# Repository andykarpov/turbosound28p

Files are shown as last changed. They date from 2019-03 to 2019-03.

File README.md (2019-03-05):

# Turbosound AVR AY Emul v1.0

TurboSound Emulator on 2x Atmega8A chips based on http://www.avray.ru project.

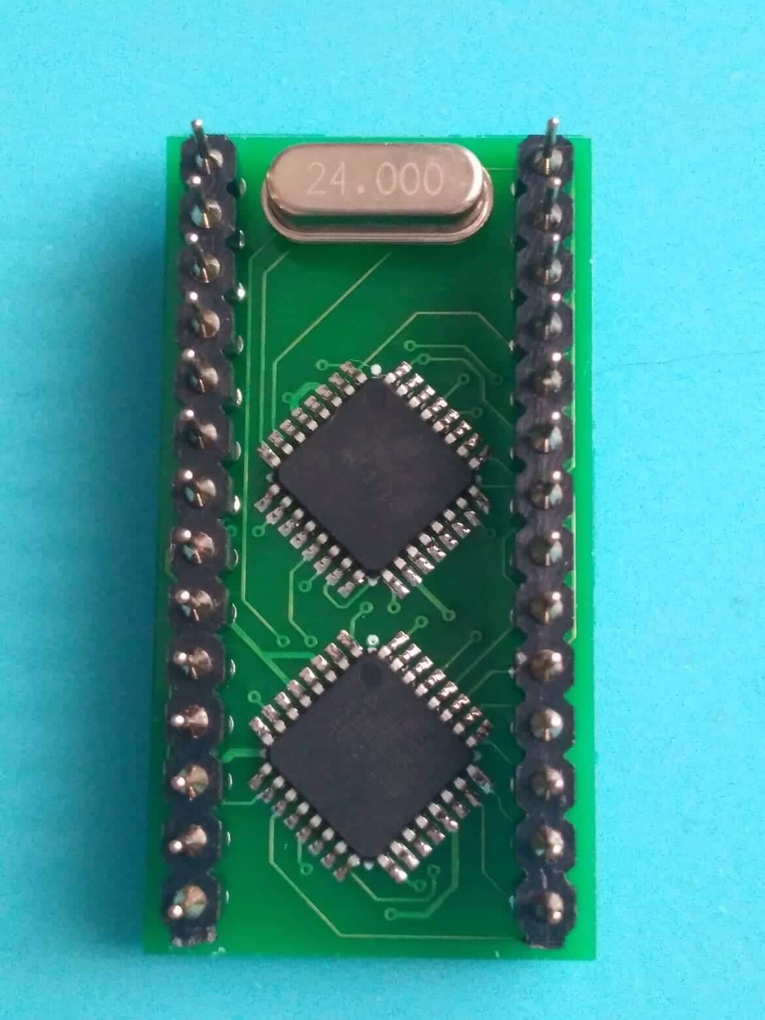
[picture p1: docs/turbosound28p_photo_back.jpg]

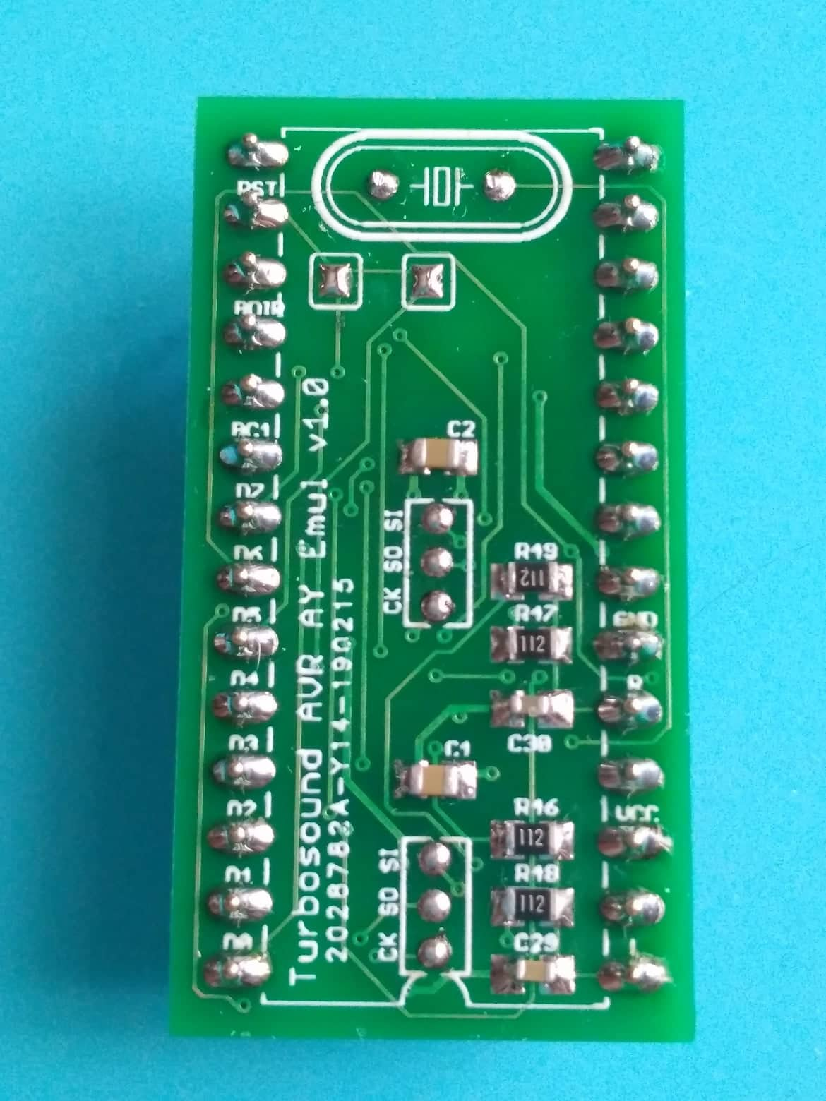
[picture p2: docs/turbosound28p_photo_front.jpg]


## How to upload the firmware
Due to there is no room for ISP connectors on the board, you need to solder a few wires directly on the board and connect them with your programmer:
- GND, VCC and RESET signals 
- CK, SO, SI as SCLK, MISO and MOSI signals 
- Do not forget to bridge solder jumpers

### Uploading:

Use avrdude and USBAsp programmer to upload firmware for each chip:

avrdude -p atmega8 -c USBasp -U flash:w:emul_230_turbosound_chip0.hex -U eeprom:w:Conf_parallel_24MHz_1_75Mhz.hex -U lfuse:w:0xCE:m -U hfuse:w:0xCF:m

avrdude -p atmega8 -c USBasp -U flash:w:emul_230_turbosound_chip1.hex -U eeprom:w:Conf_parallel_24MHz_1_75Mhz.hex -U lfuse:w:0xCE:m -U hfuse:w:0xCF:m

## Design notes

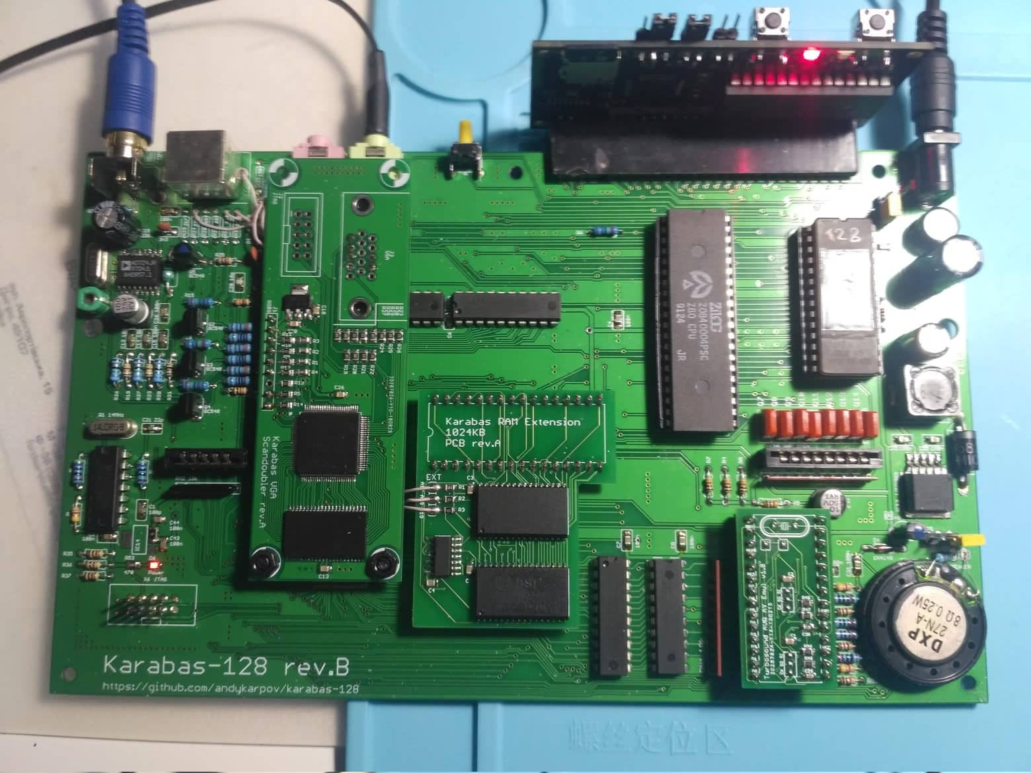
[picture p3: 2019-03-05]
docs/turbosound28p_photo_karabas.jpg

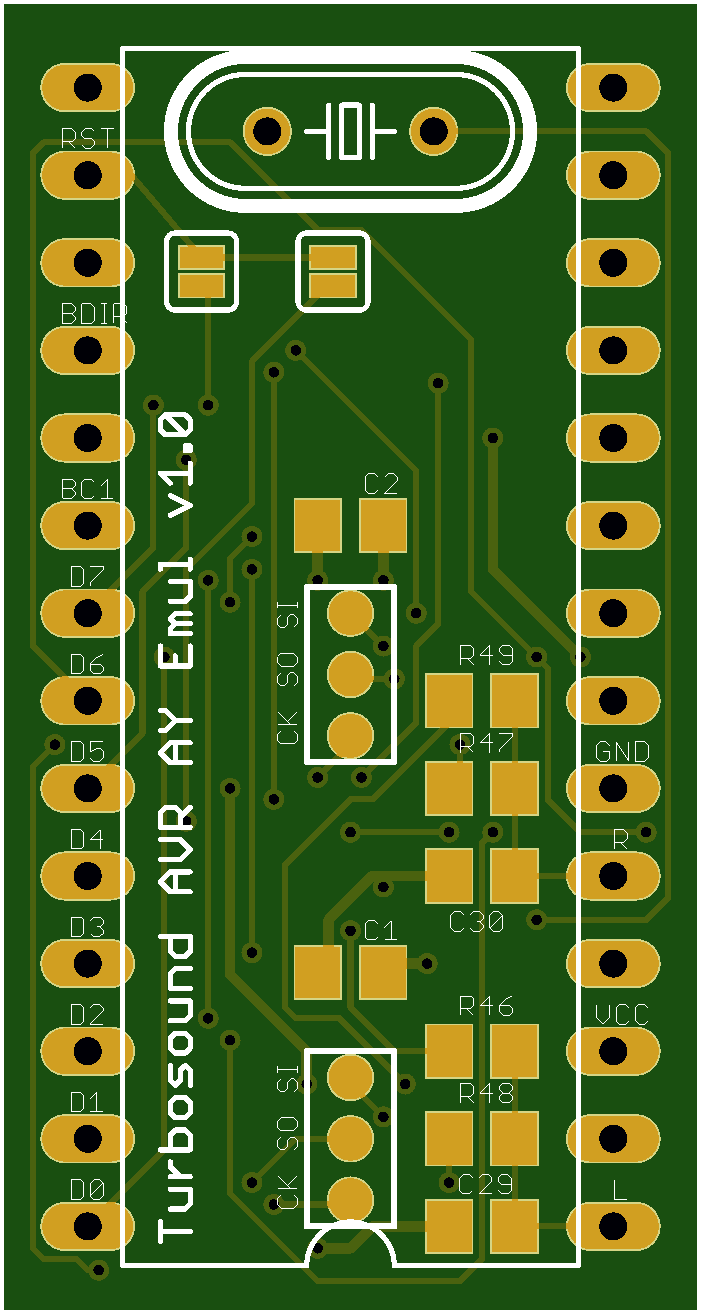
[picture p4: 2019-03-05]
docs/turbosound28p_front.png

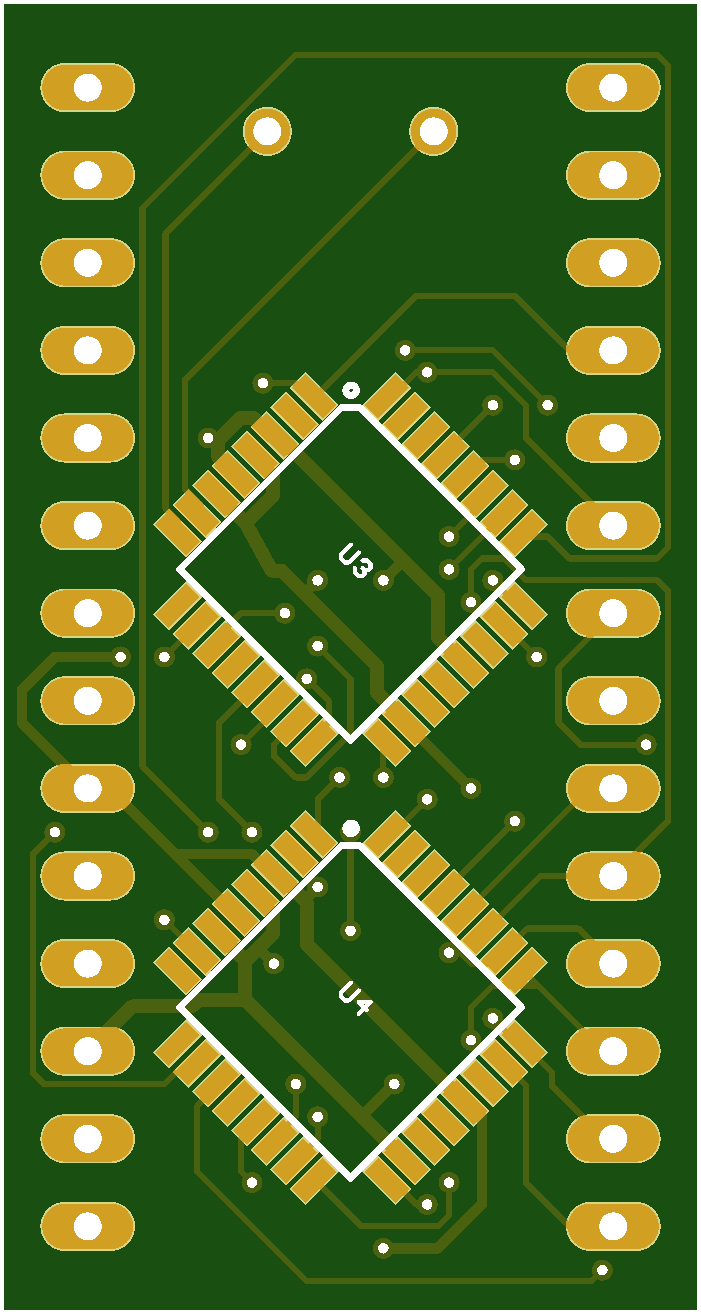
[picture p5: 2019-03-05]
docs/turbosound28p_back.png

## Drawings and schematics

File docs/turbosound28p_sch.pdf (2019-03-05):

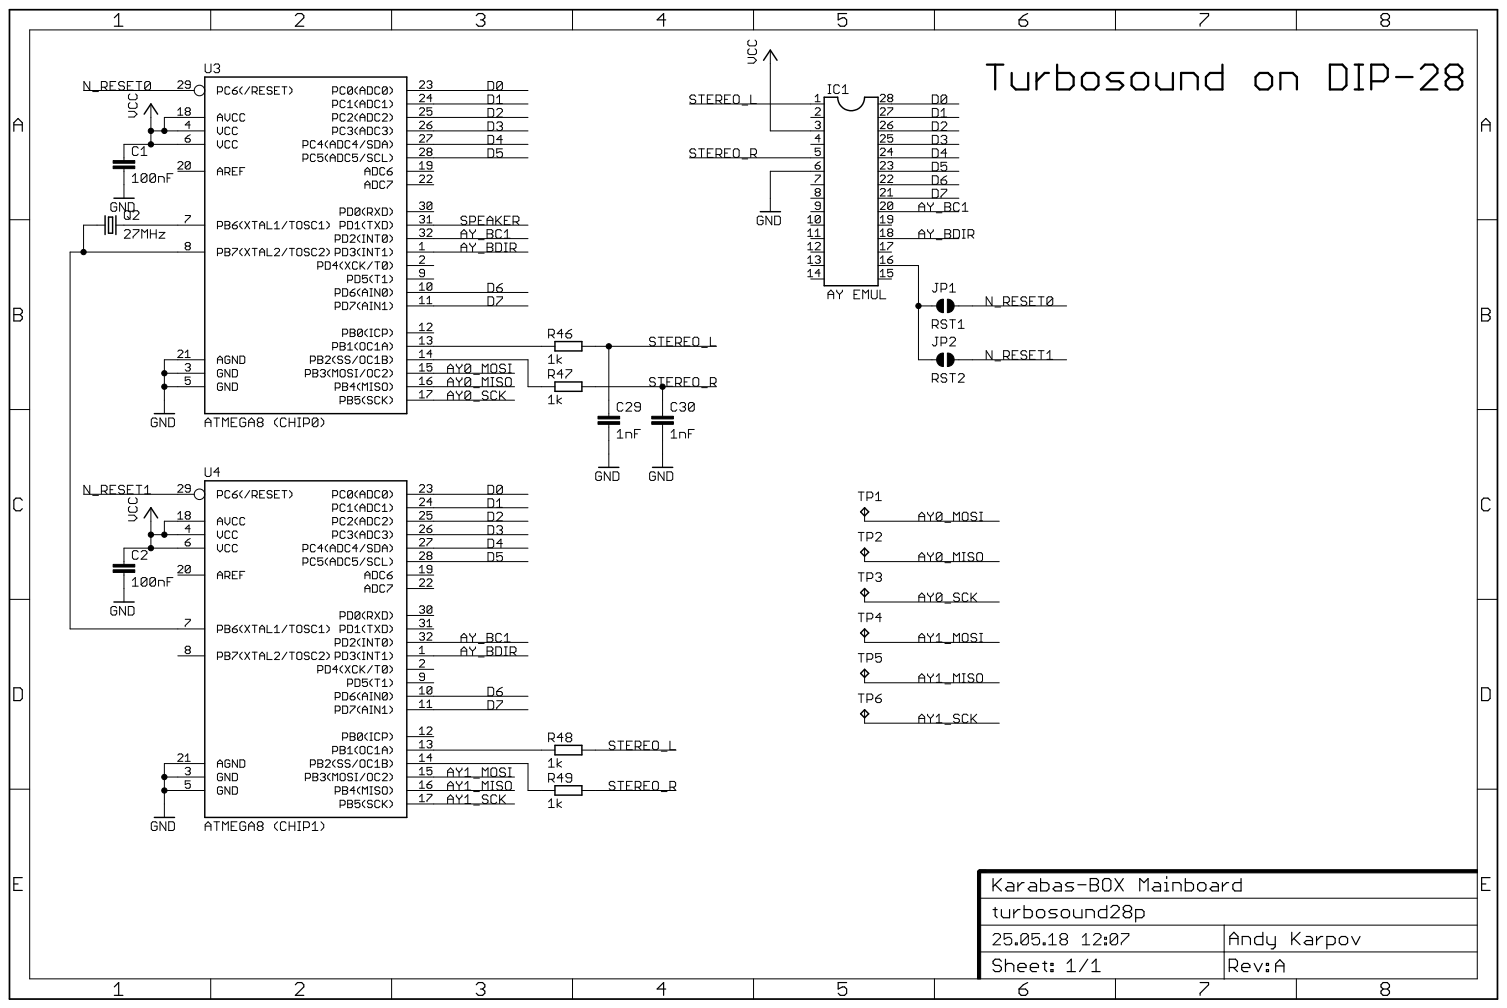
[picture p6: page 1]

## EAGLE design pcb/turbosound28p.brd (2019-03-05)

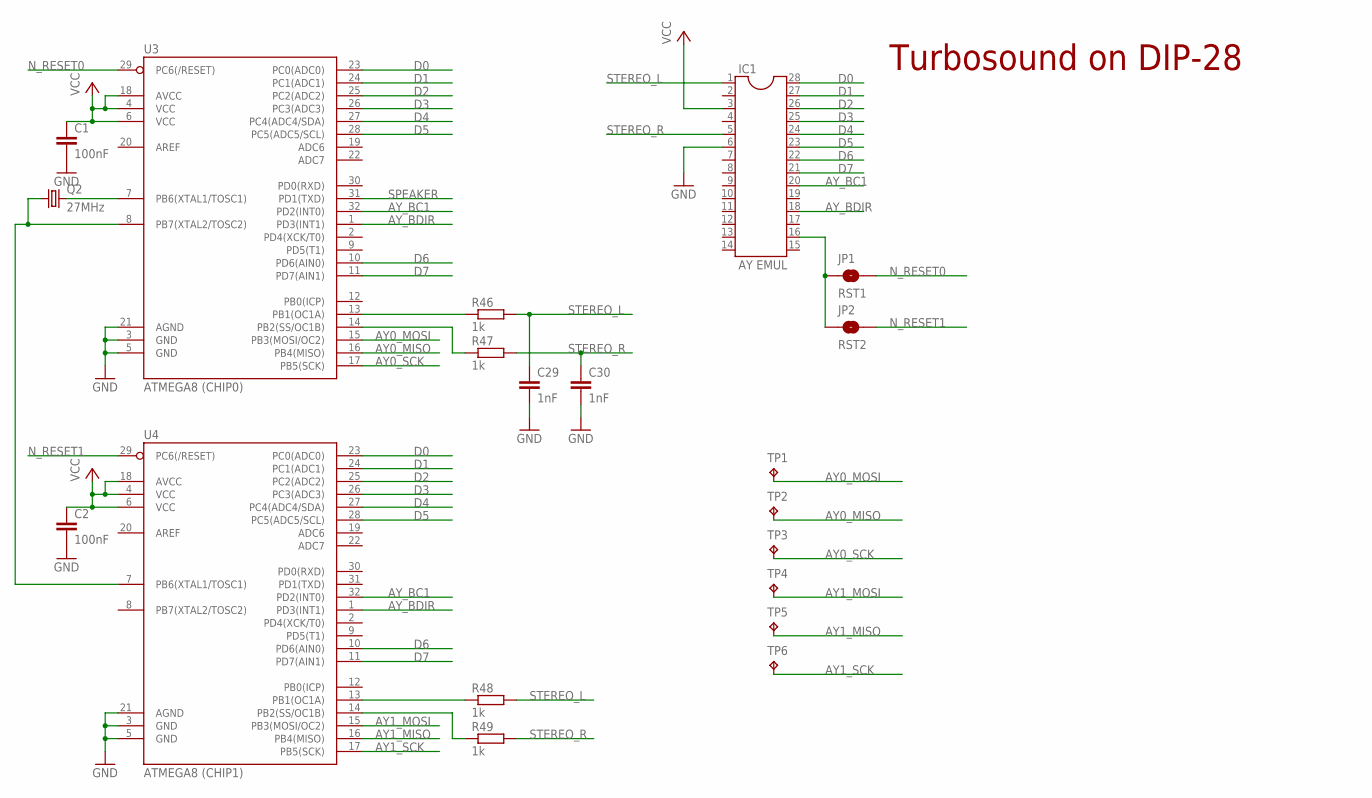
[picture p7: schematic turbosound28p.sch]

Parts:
C1, C2: 100nF; C0805
C29, C30: 1nF; C0805
IC1: AY EMUL; DIL28-6
JP1: RST1; SMT-JUMPER_2_NO_SILK
JP2: RST2; SMT-JUMPER_2_NO_SILK
Q2: 27MHz; HC49/S
R46, R47, R48, R49: 1k; R0805
TP1, TP2, TP3, TP4, TP5, TP6: TPB1,27; B1,27
U3: ATMEGA8 (CHIP0); TQFP32-08
U4: ATMEGA8 (CHIP1); TQFP32-08

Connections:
AY0_MISO: TP2.TP, U3.16 (PB4(MISO))
AY0_MOSI: TP1.TP, U3.15 (PB3(MOSI/OC2))
AY0_SCK: TP3.TP, U3.17 (PB5(SCK))
AY1_MISO: TP5.TP, U4.16 (PB4(MISO))
AY1_MOSI: TP4.TP, U4.15 (PB3(MOSI/OC2))
AY1_SCK: TP6.TP, U4.17 (PB5(SCK))
AY_BC1: IC1.20, U3.32 (PD2(INT0)), U4.32 (PD2(INT0))
AY_BDIR: IC1.18, U3.1 (PD3(INT1)), U4.1 (PD3(INT1))
D0: IC1.28, U3.23 (PC0(ADC0)), U4.23 (PC0(ADC0))
D1: IC1.27, U3.24 (PC1(ADC1)), U4.24 (PC1(ADC1))
D2: IC1.26, U3.25 (PC2(ADC2)), U4.25 (PC2(ADC2))
D3: IC1.25, U3.26 (PC3(ADC3)), U4.26 (PC3(ADC3))
D4: IC1.24, U3.27 (PC4(ADC4/SDA)), U4.27 (PC4(ADC4/SDA))
D5: IC1.23, U3.28 (PC5(ADC5/SCL)), U4.28 (PC5(ADC5/SCL))
D6: IC1.22, U3.10 (PD6(AIN0)), U4.10 (PD6(AIN0))
D7: IC1.21, U3.11 (PD7(AIN1)), U4.11 (PD7(AIN1))
GND: C1.2, C2.2, C29.2, C30.2, IC1.6, U3.3 (GND), U3.5 (GND), U3.21 (AGND), U4.3 (GND), U4.5 (GND), U4.21 (AGND)
unnamed: IC1.16, JP1.1, JP2.1
unnamed: R46.1, U3.13 (PB1(OC1A))
unnamed: R47.1, U3.14 (PB2(SS/OC1B))
unnamed: Q2.2, U3.7 (PB6(XTAL1/TOSC1))
unnamed: Q2.1, U3.8 (PB7(XTAL2/TOSC2)), U4.7 (PB6(XTAL1/TOSC1))
unnamed: R48.1, U4.13 (PB1(OC1A))
unnamed: R49.1, U4.14 (PB2(SS/OC1B))
N_RESET0: JP1.2, U3.29 (PC6(/RESET))
N_RESET1: JP2.2, U4.29 (PC6(/RESET))
SPEAKER: U3.31 (PD1(TXD))
STEREO_L: C29.1, IC1.1, R46.2, R48.2
STEREO_R: C30.1, IC1.5, R47.2, R49.2
VCC: C1.1, C2.1, IC1.3, U3.4 (VCC), U3.6 (VCC), U3.18 (AVCC), U4.4 (VCC), U4.6 (VCC), U4.18 (AVCC)

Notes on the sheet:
Turbosound on DIP-28

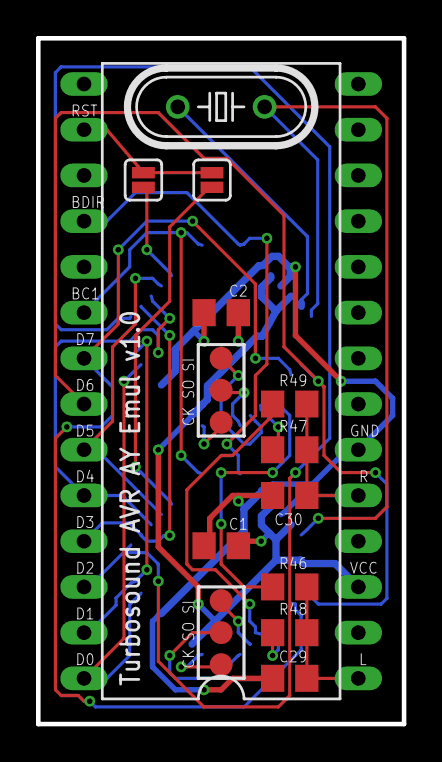
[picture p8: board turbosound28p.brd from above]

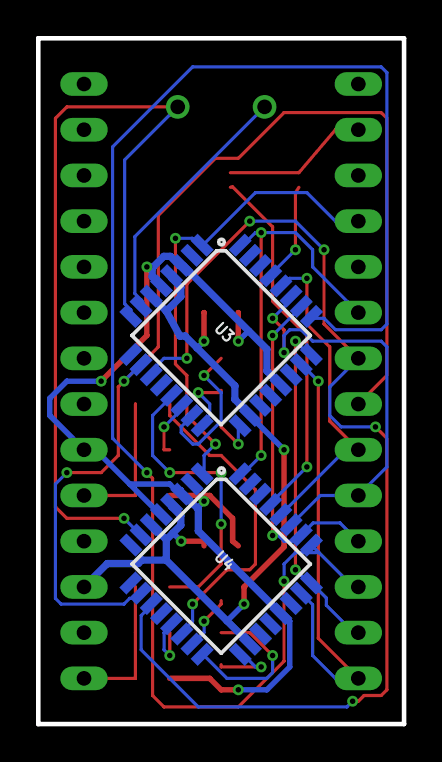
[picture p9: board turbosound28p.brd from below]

Board: 2 copper layers, 20.3 x 38.1 mm, 20 parts (2 on the bottom side), 29 nets.

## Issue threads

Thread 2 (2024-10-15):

You can compile the firmware

electroscat, 2024-10-15:
Is it possible to compile firmware for the output of A, B, C channels, instead of left and right? This is very necessary when turbosound is installed instead of AY and there is no possibility and desire to remake the authentic device.

Or get the source code for the Turbo Sound firmware, that would also help. I found the source code for the AY emulation, but the code I get when compiling is very different from the Turbo Sound code. I'll probably get the correct code with a disassembler over time, but if the authors have it, maybe they could share it?

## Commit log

2019-03-05 PCB sources and gerbers
    [turbosound28p.brd, turbosound28p.sch]
2019-03-05 Added schematics pdf

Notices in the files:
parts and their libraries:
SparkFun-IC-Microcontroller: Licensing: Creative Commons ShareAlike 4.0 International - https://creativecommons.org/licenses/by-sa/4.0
